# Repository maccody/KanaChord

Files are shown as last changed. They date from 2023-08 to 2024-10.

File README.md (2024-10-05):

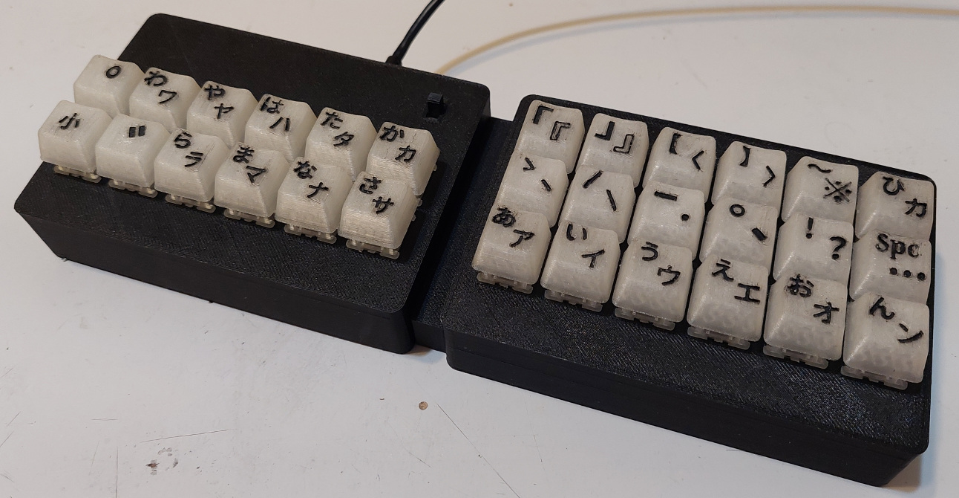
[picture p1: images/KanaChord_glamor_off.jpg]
KanaChord_glamor_off

# KanaChord Keyboard (カナコード・キーボード)
## Overview
KanaChord is an auxiliary keyboard that works in parallel with a standard English keyboard and generates Unicode keyboard macros to render Japanese Kana characters.  This allows the user to immediately start typing in the Japanese Kana, rather that installing special software and switching language input modes on a single keyboard.  KanaChord Keyboard can assist the Japanese learner by providing a means to improve their skills by writing in Japanese, in addition to reading and speaking.  Note that during the composing of this README, KanaChord Keyboard was used to type the Kana characters displayed.

The Japanese writing system consists of three components: Kanji, Hiragana, and Katakana. Kanji consists of Chinese logography and conveys main ideas and names in sentences, e.g., 私, 東京, 何 (‘I’, ‘Tokyo’, ‘what’).  There are thousands of unique Kanji characters.  Hiragana consists of 48 syllabic characters that are used for some words of Japanese origin and grammatical sentence fragments, e.g., あなた, これ, の (‘you’, ‘this’, possessive particle).  Katakana also consists of 48 syllabic characters that are used for foreign loan words and names, e.g., テーブル, クッキー, マック (‘table’, ‘cookie’, ‘Mac’).  The table below shows the syllabary of Hiragana and Katakana, known collectively as the Kana.
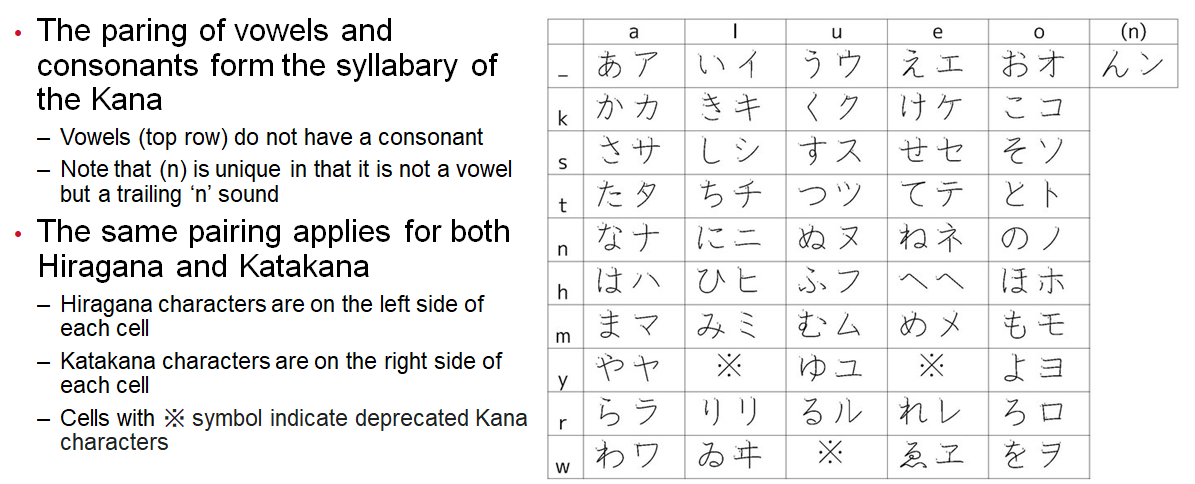
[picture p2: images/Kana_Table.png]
Kana Table


The layout of the Kana Table inspires a chording keyboard input method. Chording is where multiple keys are pressed simultaneously on the keyboard to obtain a desired character output.  The illustration below provides further explanation and demonstration of how chording is used on the KanaChord Keyboard.
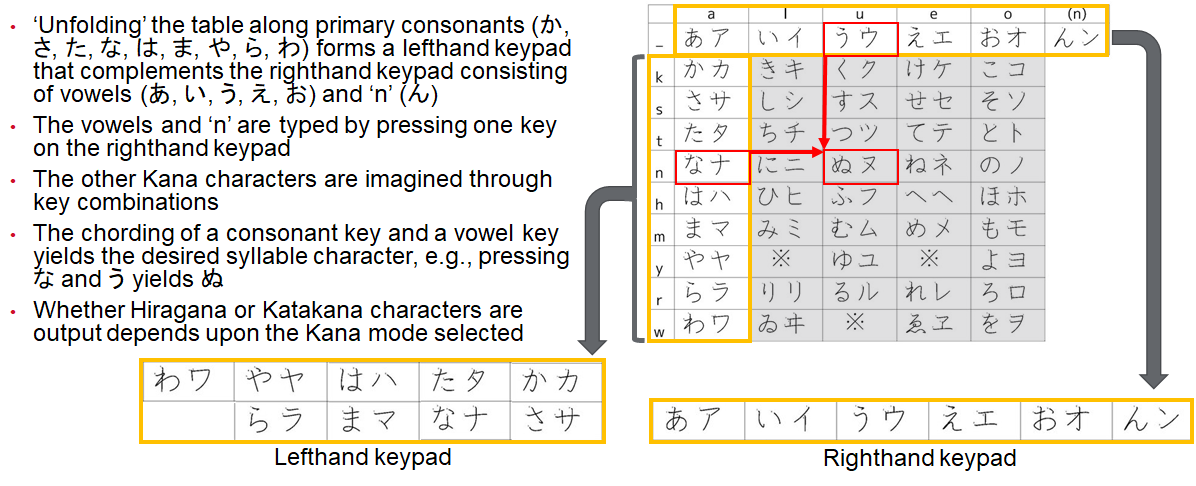
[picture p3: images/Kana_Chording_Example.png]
Kana Chording Example

## Features
KanaChord includes dynamic key coloring that provides indication of character type, Kana mode, and error feedback.  The three Shift keys on the left keypad are normally white:
- Voicing mark, a.k.a. dakuten or ten-ten (ﾞ),
- Plosive mark, a.k.a. handakuten or maru (ﾟ),
- Small characters, a.k.a. chiisai (小), also used to ‘shift’ to alternate punctuation and special characters.

Punctuation keys on the top two rows of the right keypad are also normally white:
- Vertical iteration mark (〳,〴,〵), continuation mark (ー), and separation (・) characters ,
- Sentence pausing (、) and ending characters (。, ! , ?),
- Wide space and ellipsis (…) characters,
- Commonly-used quotation (「, 」,『, 』), bracket (【, 】,〈, 〉), and special (〜,※) characters.

The Kana and horizontal iteration mark (ゝ,ゞ,ヽ,ヾ) keys are green for Hiragana mode or blue for Katakana mode, as selected by the mode key (ひカ) at upper right-hand corner of the right keypad.
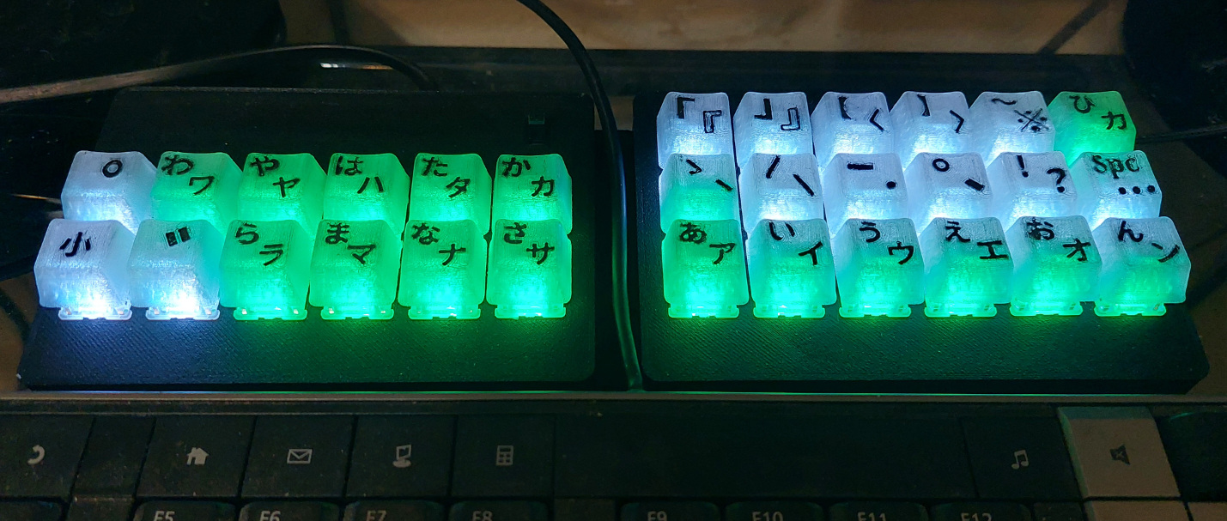
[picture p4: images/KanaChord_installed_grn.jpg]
KanaChord_installed_grn

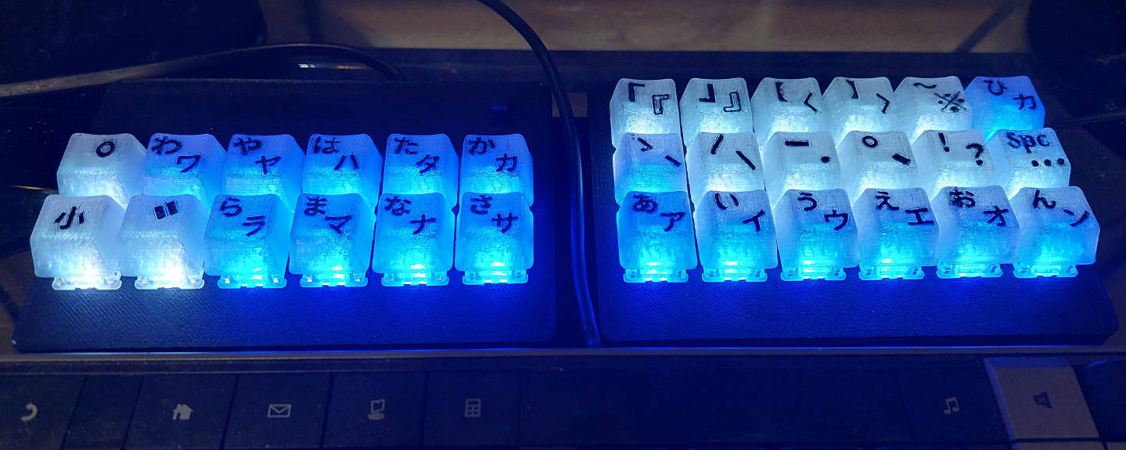
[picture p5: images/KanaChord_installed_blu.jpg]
KanaChord_installed_blu


Feedback is provided to the user for incorrect key combinations by changing those keys red.  Releasing the keys will cause the keys to revert to their original colors.  Some examples are provded below:

Keyboard error lighting with press of ! and お key combination.
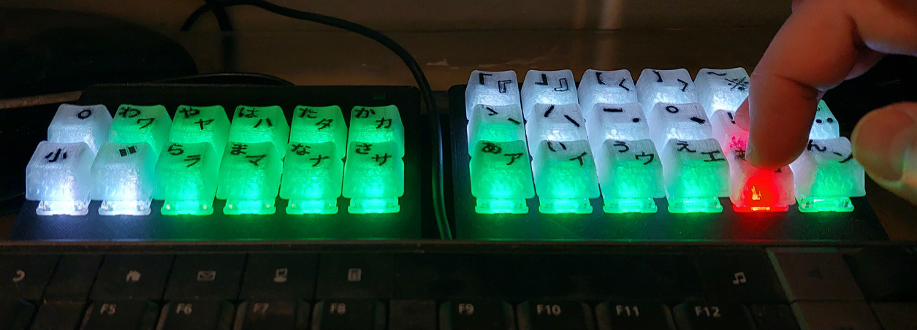
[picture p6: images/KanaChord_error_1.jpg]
KanaChord_error_1


Keyboard error lighting with press of ﾞ, な, and あ key combination.
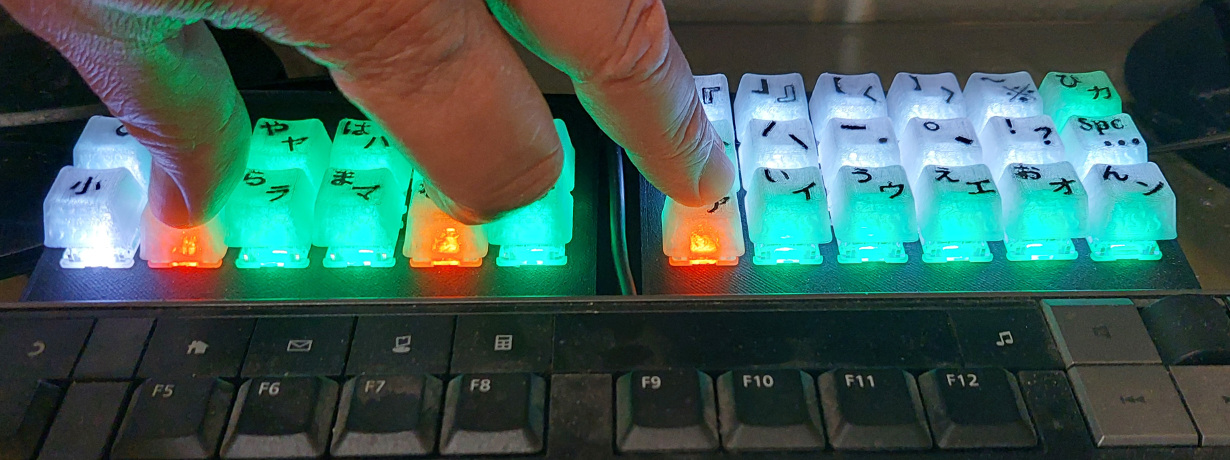
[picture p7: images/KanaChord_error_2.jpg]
KanaChord_error_2


A slide switch above the か key provides three user-selectable Unicode key sequences to support different computer platforms:
- Four-characer hexidecimal Unicode value, followed by Alt-X: Supports Microsoft Word and Wordpad, and LibreOffice Writer.
- Ctrl-Shift-u, followed by four-character hexidecimal Unicode value: Supports Linux applications like LibreOffice Writer and Firefox.
- Option key, followed by four-character hexidecimal Unicode value: Support MacOS applications (not yet tested).

## Implementation Overview
The primary electical componets of the KanaChord Keyboard are a Raspberry Pi Pico (RP2040) microcontroller, an Adfruit NeoKey 5x6 Ortho Snap-Apart keyboard PCB, and thirty Cherry MX mechanical key switches.  The keycaps and keyboard enclosure are 3D printed designs created with TinkerCAD.  Blank keycaps and an OpenSCAD tight-fit box generator were found on Thingiverse.  No special hardware, such as screws are needed to mount the electrical components and assemble the enclosure.  Details on the electronics, enclosure, and their assembly can be found in the hardware subdirectory.

Kanachord's software was developed with the Arduino IDE (version 1.8.19) and Earle Philhower's RP2040 board support package.  The USB Keyboard library, Adafruit Neopixel library, and Mark Stanley's Key and Keypad libraries provided critical software functions.  Details on the software can be found in the software subdirectory.

## Hardware and Software Licenses
Cc_by-nc-nd_icon svg
KanaChord's circuit design and the STL files for the keycaps, component mounting parts, and enclosure parts are placed under Creative Commons Attribution-NonCommercial-NoDerivatives license.

GNU_GPL_V3
KanaChord's source code that I wrote (KanaChord.ino, kana.h, kbd_mgt.cpp, and kbd_mgt.h) are placed under GNU General Public License, Version 3.0.

The slightly-modified versions of Mark Stanley's Key and Keypad libraries (Key2040.cpp, Key2040.h, Keypad2040.cpp, and Keypad2040.h) fall under the license of the original sources.

## Feedback is Welcome!
My goal is to provide an axuilary keyboard that is useful to those who want to start writing in Japanese, while learning Japanese.  I hope to have provided operational features, keycaps, and Asian special characters that would most likely be used.  If you have recommendations for additional features, alternate keycaps, or Asian special characters, please let me know.  I will accomodate as many recommendations as feasible.

## The Future of KanaChord Keyboard
As, mentioned above, KanaChord Keyboard outputs only Kana Unicode, not Kanji Unicode.  This is an obviously glaring omission for writing in Japanese.  A software IME (Imput Method Editor) that accepts Kana Unicode input could be used to make up for this shortcoming.  This takes away from the goal of not needing to install special software.

To that end, I have developed the next version of this keyboard, which also outputs Kanji Unicode. I call it [KanaChord Plus Keyboard (カナコード・プラス・キーボード)](https://github.com/maccody/KanaChordPlus), which can output Unicodes for over 6,100 of the most commonly-used Kanji and over 6,200 of the most commonly-used Japanese words containing Kanji. The user can select them as they type the appropriate onyomi (Chinese), kunyomi (Japanese), or nanori (name) readings using the Kana. This will help the user learn Kanji, as they learn the proper readings and pronunciations from the Kana typed.

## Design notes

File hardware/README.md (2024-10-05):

# KanaChord Hardware

## Electronics Components
KanaChord Keyboard uses following electronics parts:
- 1 x Raspberry Pi Pico microcontroller
- 1 x [Adfruit](https://www.adafruit.com) [NeoKey 5x6 Ortho Snap-Apart Mechanical Key Switches w/ NeoPixel - For MX Compatible Switches](https://www.adafruit.com/product/5157)
- 30 x Cherry MX RGB frame-mount mechanical key switches, e.g., [Cherry MX Brown Switches](https://www.cherrymx.de/en/cherry-mx/mx-original/mx-brown.html) (does not count spares)
- 1 x BC547 (or equivalent) NPN transistor
- 1 x 2.2 Kohm 1/8 Watt resistor
- 1 x 6.8 Kohm 1/8 Watt resistor
- 1 x Three-position (NC-NO-NC) slide switch (E-Switch Slide Switches 500SSP3S2M1QEB, Mouser 612-500SSP3S2M1QEB)
- 27 x 0.1" Spacing Row Right Angle Headers (does not count spairs), e.g., [Schmartboard brand](https://schmartboard.com/qty-10-0-1-spacing-40-single-row-right-angle-headers-920-0076-01/)
- 2 x Seven-position ITT connector shell - (e.g., Adafruit [Large Single Row Housing Pack](https://www.adafruit.com/product/3146))
- 3 x Five-position ITT connector shell - (e.g., Adafruit [Small Single Row Wire Housing Pack](https://www.adafruit.com/product/3145))
- 1 x Four-position ITT connector shell - (e.g., Adafruit [Small Single Row Wire Housing Pack](https://www.adafruit.com/product/3145))
- 1 x Three-position ITT connector shell - (e.g., Adafruit [Small Single Row Wire Housing Pack](https://www.adafruit.com/product/3145))
- 27 x Female crimp contact pins (does not count spares)
- 5 x Male crimp contact pins (does not count spares)
- 1 x 12 inches of Forty-conductor ribbon cable 
- 1 x USB A to USB Micro B cable
- Heat-shrink tubing for enclosing the unidirectional level shifter

## Keyboard Schematics
Below is a pictorial schematic of the keypad portion of the KanaChord keyboard.

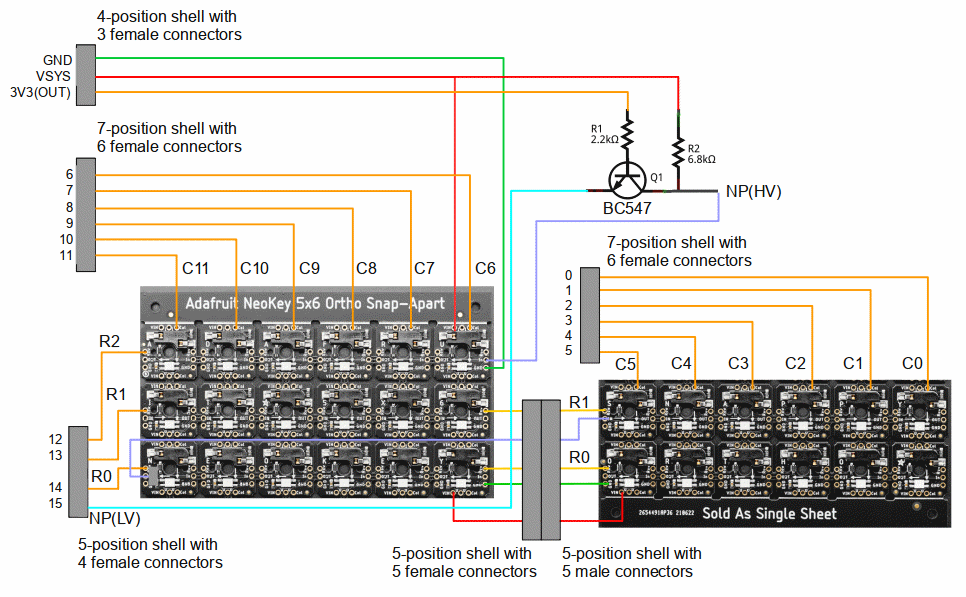
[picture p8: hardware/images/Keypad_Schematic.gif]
Keypad_Schematic


While the Neopixels of the Ortho Snap-Apart board can opperate at 3.3 Volts, the 3.3-Volt regulator on the Pico cannot supply enough current.  Therefore, the Neopixels are powered by the Pico's 5-Volt VSYS output.  Consequently, a unidirectional level shifter is used to convert the low-voltage Neopixel signal, NP(LV), to a high-voltage Neopixel signal, NP(HV).  The BC547 and resistors are used to implement the unidirectional level shifter circuit.

Below is a pictorial schematic of the Raspberry Pi Pico portion of the KanaChord keyboard.

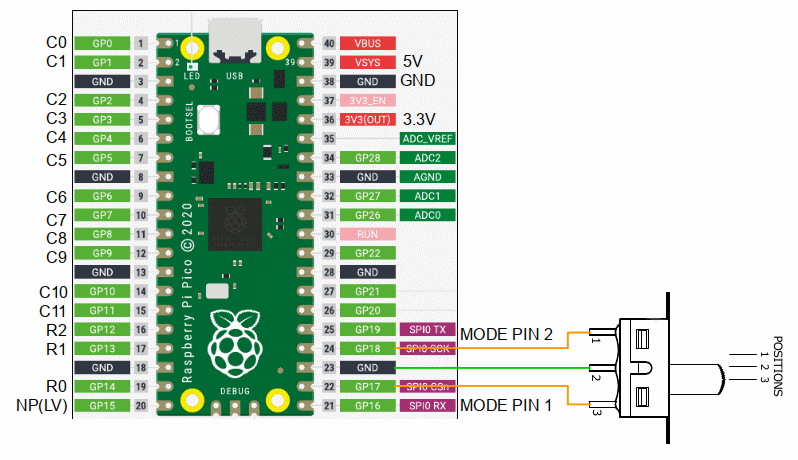
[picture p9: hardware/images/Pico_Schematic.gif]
Pico_Schematic


The right-angle header pins are soldered in 'gull-wing' fashion to pins 1 through 20, 22 through 24, and 36 through 39 of the Pico.  Note that the slide switch is not soldered directly to the Pico.  Instructions found in the Electrical Assembly will describe the wiring harness that is used.

## Electrical Assembly 
### Keypad Preparation 
Before assembly, the snap-apart keyboard must be broken into two pieces to form two PCBs (Printed Circuit Boards) for the left and right keypad assemblies.  As shown in the pictoral schematic above and the pictures below, cut apart the keyboard so that the bottom two rows form the left keypad and the top three rows form the right keypad.  Rather than actually bending the PCB to snap it, it is recommended to use a thin saw to cut the bridges between the rows.  DO NOT cut off the blank sections on the top and bottom of the PCB, as the mounting holes will be used to help position the keypads in the keyboard enclosure.

### Left Keypad Wiring 
The wiring of the left keypad assembly is shown in the picture below.  Take note the direction and length of the wires that extend from the left-hand keypad PCB.

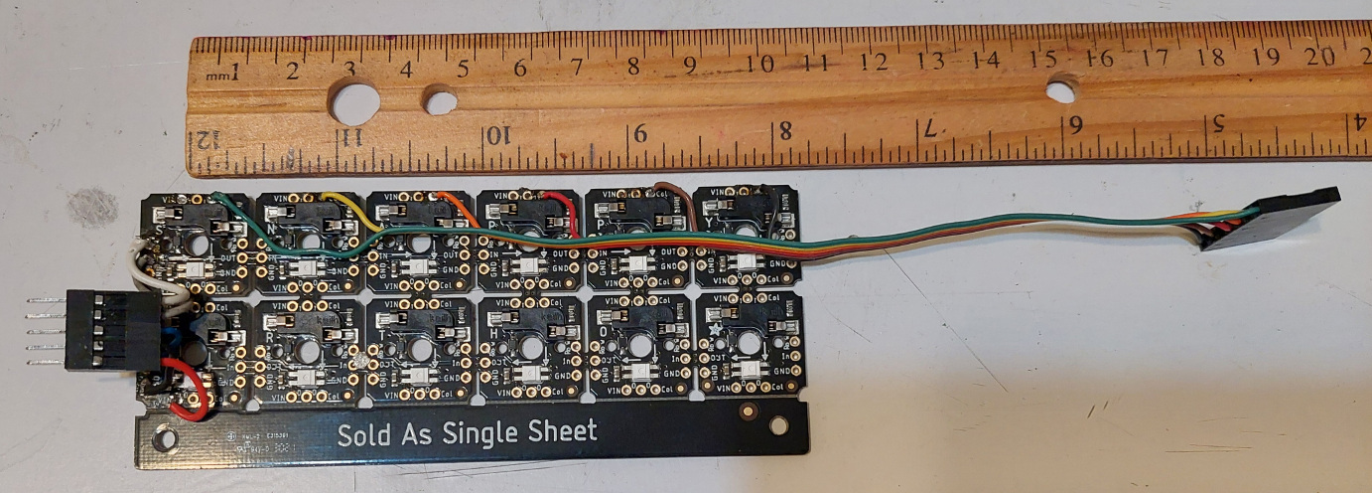
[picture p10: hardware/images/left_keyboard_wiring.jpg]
left_keyboard_wiring


First, cut a six-conductor section of ribbon cable with a length of approximatly 19 cm (7.5 inches).  This will be the column cable for the left keypad.  Separate out the individual conductors for about 3 cm (one inch), attach six (6) female crimp terminals, and insert the terminals into a seven (7) terminal connector shell.  Note that there will be an unused place between the terminal pins for Columns 1 and 2, which is Ground Pin 3 on the Pico. Then, as shown in the picture, start at the left end of of the keypad PCB and solder a conductor to a column solder pad. Work towards the right end of the keypad, shortening the length of the conductor to match to the column solder pad location, while keeping the ribbon cable parallel to the PCB. Note that during installation, this cable will fold over to attach to Pins 1 through 7 on the Pico.

Next, create the male keypad interconnect harness using five (5) male crimp terminals. This is a short cable, with a length of approximately 3 cm (1.25 inches), it is recommended to use separate wires, rather than a ribbon cable. A five (5) terminal connector shell is used for this harness. Use the pictorial schematic above for wiring directions. This completes the wiring of the left keypad assembly.

### Right Keypad Wiring 
The wiring of the right keypad assembly is shown in the picture below. Again, take note of the direction and length of the wires that extend from the right-hand keypad PCB.

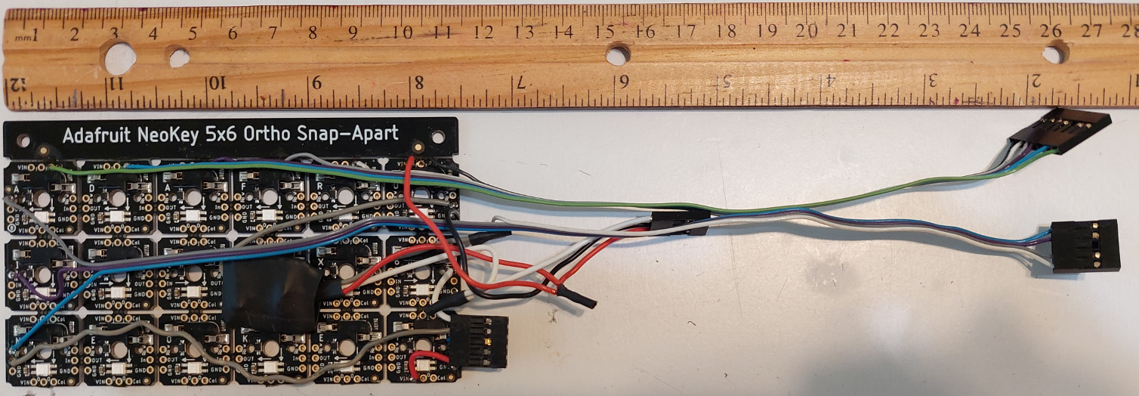
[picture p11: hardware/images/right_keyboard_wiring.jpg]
right_keyboard_wiring


First, cut a six-conductor section of ribbon cable with a length of approximatly 26 cm (10.25 inches).  This will be the column cable for the right keypad.  Separate out the individual conductors for about 3cm (1.25 inches), attach six (6) female crimp terminals, and insert the terminals into a seven (7) terminal connector shell.  Note that there will be an unused place between the terminal pins for Columns 9 and 10, which is Ground Pin 13 on the Pico. Then, as shown in the picture, start at the left end of of the keypad PCB and solder a conductor to a column solder pad. Work towards the right end of the keypad, shortening the length of the conductor to match to the column solder pad location, while keeping the ribbon cable parallel to the PCB. Note that during installation, this cable will fold over to attach to Pins 9 through 15 on the Pico.

Next, create the female keypad interconnect harness using five (5) female crimp terminals. This is a short cable, with a length of approximately 3 cm (1.25 inches), it is recommended to use separate wires, rather than a ribbon cable. A five (5) terminal connector shell is used for this harness. Use the pictorial schematic above for wiring directions.

Now, cut a four-conductor section of ribbon cable with a length of approximatly 28 cm (11 inches).  This will be the row cable for the right keypad.  Separate out the individual conductors for about 3 cm (1.25 inches), attach four (4) female crimp terminals, and insert the terminals into a five (5) terminal connector shell.  Note that there will be an unused place between the terminal pins for Rows 0 and 1, which is Ground Pin 18 on the Pico. Note that three of the ribbon cable conductors attach to the Row solder pads on the right keyboard PCB, while one conductor attaches to the signal input of the level shifter circuit. Note that during installation, this cable will fold over to attach to Pins 16 through 20 on the Pico.

Assmble the unidirectional level shifter circuit on a small piece of prototyping board with solder pads or as otherwise desired.  The idea is to keep the resulting assembly small and relatively flat.  In the implementation shown in the picture, judicious application of heat-shrink tubing was performed to prevent short circuits. ***Note: Instructions for constructing of an equivalent, free-form-wired level shifter can be found on the [KanaChord Plus Hardware page.](https://github.com/maccody/KanaChordPlus/tree/main/hardware#level-shifter-assembly)***  The circuit is wired into the power harness, which is approximately 10 cm (3.5 inches) long.  The power harness has three (3) female crimp connectors that are inserted into a four (4) terminal connector shell.  Note that there will be an unused place between the Ground and 3V3(OUT) pins, which is the 3.3V_EN pin 37 on the Pico.  Consult the pictorial schematic above for the wiring of the level shifter circiut, with the output of the level shifter connected to the Neopixel input and the power harness 5V and Ground to the right keyboard PCB. During installation, the power harness connector will attach to Pins 36 through 39 on the Pico. This completes the wiring of the right keypad assembly.

The macro mode slide switch is soldered to a three-wire harness that is 5 cm (2 inches) long.  The harness has three (3) female connector pins crimped on and placed within a three-position connector shell. Consult the pictorial schematic above for the wiring of the switch harness. During final assembly, the connector will be placed on the header pins at positions 22 through 24.

## 3D-Printed Keycaps
The keycaps for the KanaChord Keyboard were created in TinkerCAD, as shown in the illustration below.  The STL files for the left-hand and right-hand keycap sets can be viewed with the Github STL viewer by clicking on the STL files listed above.

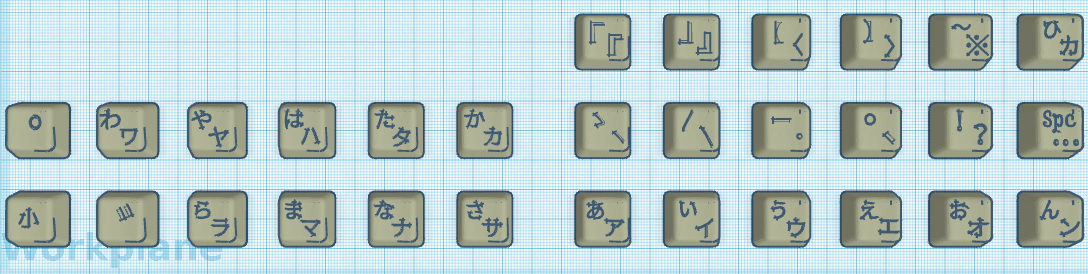
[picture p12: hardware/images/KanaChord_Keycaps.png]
KanaChord_Keycaps


The blank keycap from makerhack's (Chris Garrett) [Custom Cherry MX Keycaps](https://www.thingiverse.com/thing:4702109) was used as the source keycap.  The design is licensed under the [Creative Commons - Attribution license](https://creativecommons.org/licenses/by/4.0/). The Kana and special charaters are text objects converted to TinkerCAD 'holes' that are combined with blank keycaps to form insets. The keycaps were sliced with Cura using the Standard Quality (0.2mm) setting, with 20% infill using the gyroid infill pattern, and Tree supports were used. The keycaps were printed with untinted PLA to allow light from the Neopixels to shine through. After printing, the insets were filled with black acrylic paint, followed by a coat of flat, clear enamel paint.

## 3D-Printed Enclosure
The enclosure for the KanaChord Keyboard was also created in TinkerCAD, as shown in the illustrations below.  The STL files for the individual components of the enclosure can be viewed with the Github STL viewer by clicking on the STL files listed above.  **NOTE: The STL files for the case, base, and foot parts have been updated since the images below were generated.  The assembly process is still the same.**

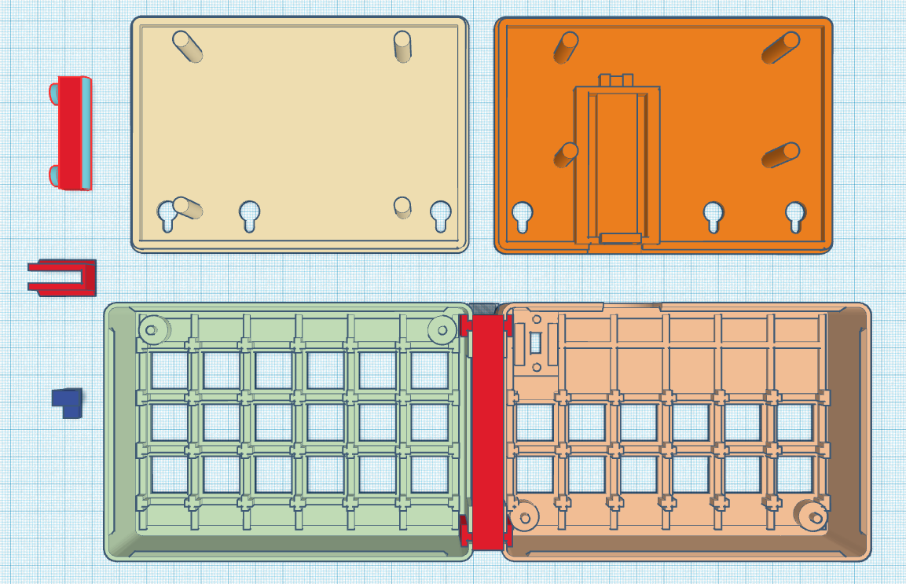
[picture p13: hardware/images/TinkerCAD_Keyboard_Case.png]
TinkerCAD_Keyboard_Case


The left and right keycase enclosures were created using 0707070user's OpenSCAD program [Customizable snap-fit electronics project box enclosure](https://www.thingiverse.com/thing:2866563). It is licensed under the [Creative Commons - Attribution license](https://creativecommons.org/licenses/by/4.0/). The enclosure components are flipped so tha the lids now act as baseplates for the keyboard enclosure. The enclosures were edited to create the key switch holes of the integral keyplates, the switch and Pico mounts, and pass-through holes for the keyboard feet, and the USB cable.  

The enclosure was designed in halves to fit on the build plate of a Crealty Ender 3 Pro 3D printer.  All components were sliced with Cura using the Low Quality (0.28mm), with 20% infill using the standard in-fill pattern, and no supports were used.  The case components were prited in black PLA, although any color can be used, if desired.

## Mechanical Assembly

### Applying PCB Cushions
The keypad PCBs are connected to the key switches via sockets.  To prevent the PCBs from coming loose from the key switches, supports are provided to keep the PCBs in place. Two of these supports are shown in the photo below.

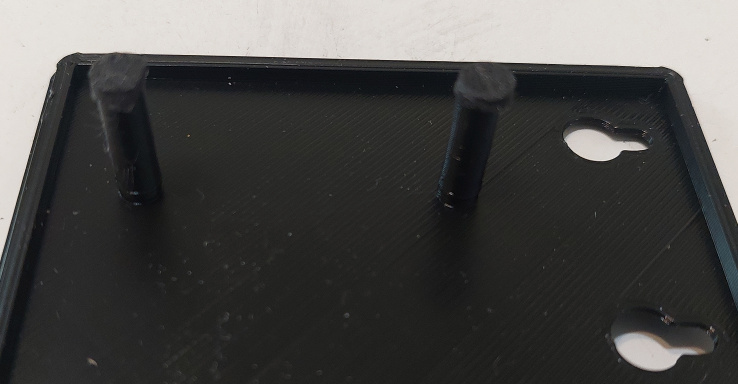
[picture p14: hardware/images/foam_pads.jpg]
foam_pads


The height of each support is such that there is about a 2mm (0.1 inch) gap from the top of the supports to the underside of the PCBs. To fill in the gap, a small disc of 2mm-thick craft foam is attached to top of each support with double-sided adhesive tape.  One way to make the discs is to apply a strip of double-sided tape to a piece of craft foam.  A single-hole hole punch is used to create the discs with the adhesive tape also cut to the same size as the disc.  Eight (8) discs will be needed for the supports.

### Mounting the Raspberry Pi Pico
The Pico is mounted to the left keyboard base by first inserting the end with the USB connector under the bridge of the processor mount at the edge of the keyboard base. Once this is done, push the opposite end of the Pico down into the depression of the processor mount. Finally, slide the retaining clip into the notches in front of the processor mount until the tab of the retaining clip is securely on top of the end of the Pico.

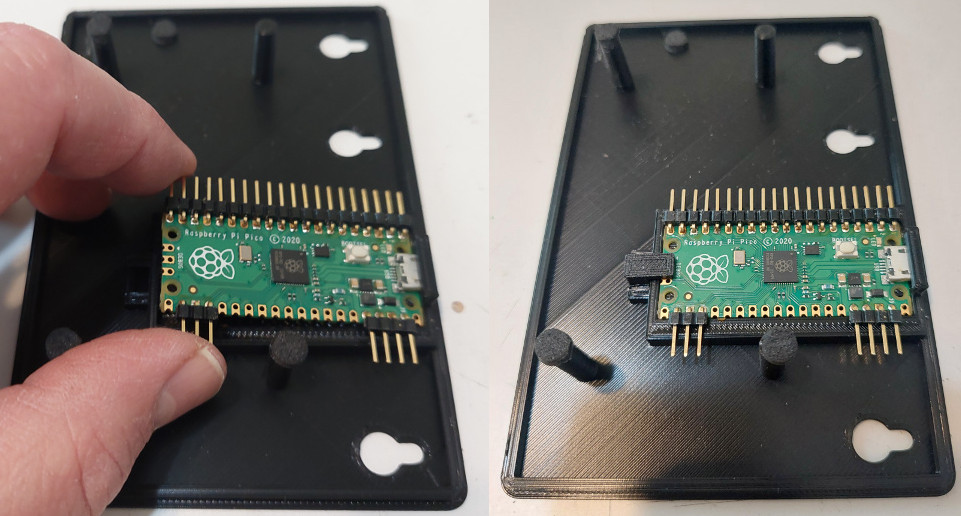
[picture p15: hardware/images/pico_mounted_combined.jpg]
pico_mounted_combined


### Mounting the Macro Mode Switch
The Macro Mode slide switch is placed into the left keyboard enclosure such that the switch handle passes through the hole in the enclosure and the tabs on each end of the switch sit around the two retaining pegs.  Once in place, the switch clip is slid into place around the switch.  Make a note of the order of the wires on the switch and connector, so that the connector is properly connected to the Pico later.

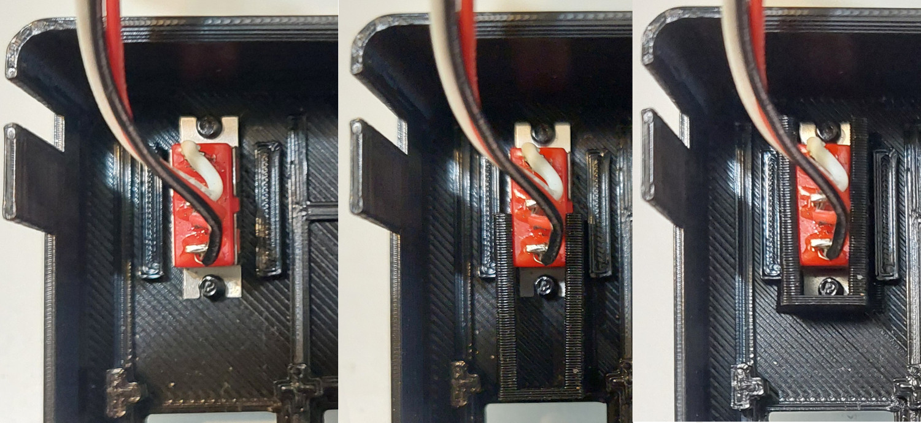
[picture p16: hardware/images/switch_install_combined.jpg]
switch_install_combined


### Break-in the Key Switch Sockets
Prior to mounting the key switches and keypad PCBs, it is highly recommended to 'break in' the key sockets on the keypads.  This is done by inserting a key switch into each key socket at least once.  The key sockets are a little 'stiff' with the first insertion of a switch.  Doing this will make it a bit easier to mount the key switches into the keypads and reduce the possibility of bending the tabs on the key switches.

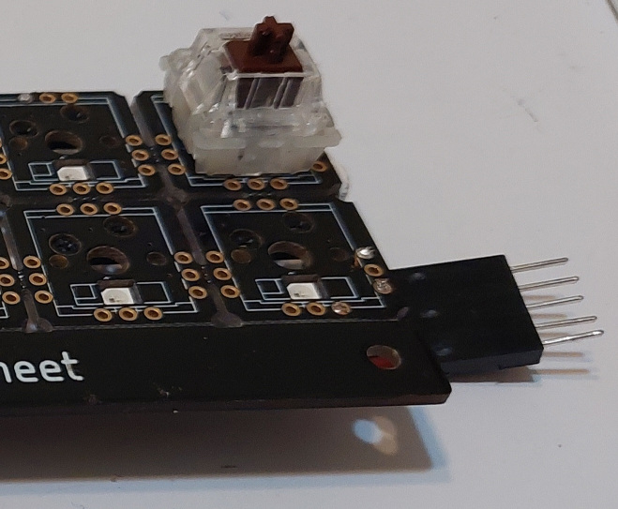
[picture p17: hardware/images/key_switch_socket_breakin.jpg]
key_switch_socket_breakin


### Preparing the Enclosures for the Key Switches
It may be necessary to slightly widen the keyplate holes on the enclosures prior to attaching the key switchs and keypads.  For any give hole, try to insert a key switch without any widening.  If a switch plugs in easily, then no widening is needed.  For those holes needing widening, use a flat-sided jewler's file to slightly widen all sides of the hole.  In practice, it should not take much filing to allow a switch to plug in easily.

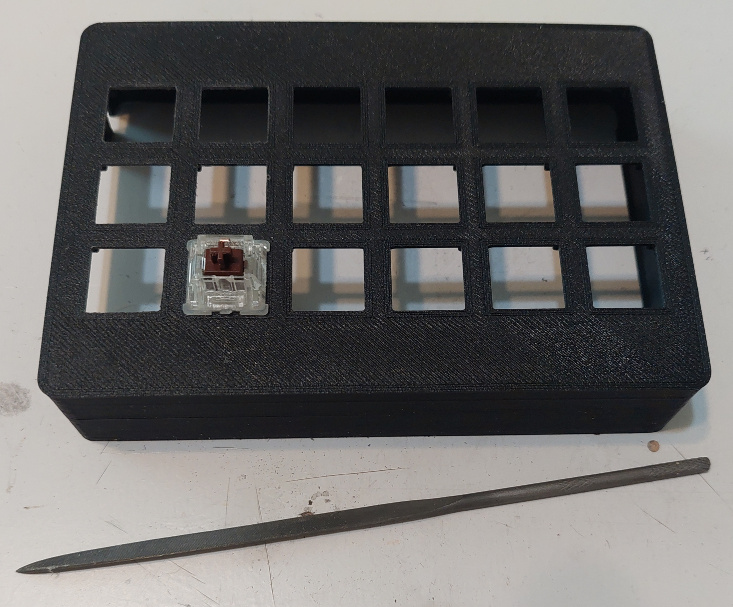
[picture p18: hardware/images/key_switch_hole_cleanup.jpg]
key_switch_hole_cleanup


### Mounting Key Switches and Keypad PCBs to the Enclosures
**NOTE: It has been determined that the positions of the mounting holes on the keypad PCBs can be a bit variant.  If it is found that the kepads will not fit on the mounting posts, it is recommended that the posts be removed.  This results in making it a bit more difficult to initially align the keypad PCBs with the keyplate holes and key switches.**

**UPDATE: The spacing of the mounting posts on the keyboard cases have been updated to better fit the mounting holes on the keypad PCBs.  Follow the recommendation above if fitting problems still occur.**

First, slide on the keyboard bracket on to the right keyboard enclosure.  Make sure that the bracket is inserted such that the side with the tabs flush to the bracket face is inserted first.  Next, place the three-row keypad PCB into right keyboard enclosure. The female keyboard interconnect connector, the column and row cables, and the power harness should slide through the opening in the keyboard bracket. Use the mounting pins, if present, to align the key sockets with the holes of the integral key plate.

Start at one end of the enclosure and insert a key switch through the hole of the keyplate into the socket of the PCB. Place a finger against the key socket, on the bottom side of the PCB, to support key switch insertion. Having a keycap on the switch will make it easier to press the switch in.  Once the switch is inserted, go to the opposite end and insert another key switch as before.  Doing this will stablize the PCB position for inserting the rest of the key switches.  Working from the ends towards the center of the enclosure, plug in more keys until all eighteen switched are plugged in.

Now insert the left keypad PCB into the left keyboard enclosure.  As with the right keypad, align the key socket with the holes in the integral keyplate.  Insert the key switches, again working from both end of the enclosure to the center.  Once all of the key switches are inserted, slide the left keyboard enclosure onto the other side of the keyboard bracket.  While doing this, fold up the male keyboard connector to clear the bracket and then plug it into the female keyboard connector.

After completing these steps the keyboard assembly show look as shown in the picture below.

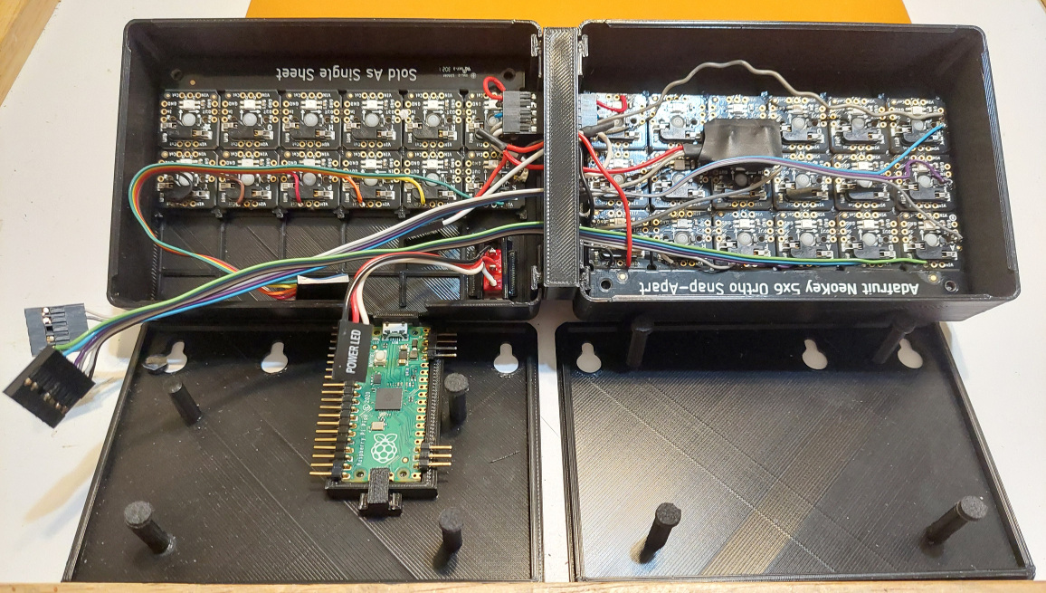
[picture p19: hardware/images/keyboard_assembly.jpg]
keyboard_assembly


### Inserting Connectors onto the Pico
Insert the power harness connector on to pins 36 through 39 on the Pico.  Make sure that the 3.3V wire is connected to 3V3(OUT) (pin 36), the ground wire is connected to GND (pin 38), and the 5V wire is connected to VSYS (pin 39). Then, connect the column cable for the left keypad to pin 1 through pin 7 on the Pico.  The Column 0 (C0) wire should be connected to pin 1.  The picture below shows how the connections should look.

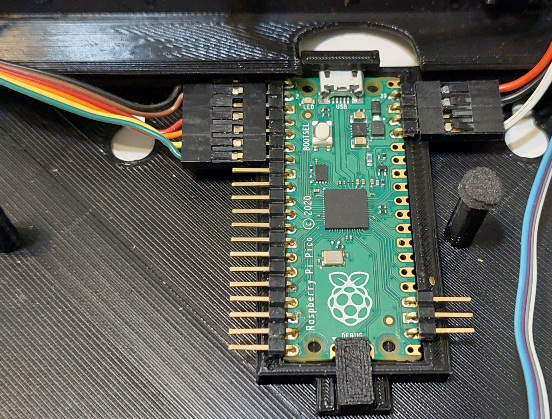
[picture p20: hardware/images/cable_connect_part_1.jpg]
cable_connect_part_1


Next, insert the column cable for the right keypad to pin 9 through pin 15 on the Pico. The Column 6 (C6) wire should be connected to pin 9.  Then, connect the row cable for the right keypad to pin 16 through pin 20 on the Pico. The Row 2 (R2) wire should be connected to pin 16 and the Neopixel low voltage (NP(LV)) wire should be connected to pin 20. The picture below shows how the connections should look.  

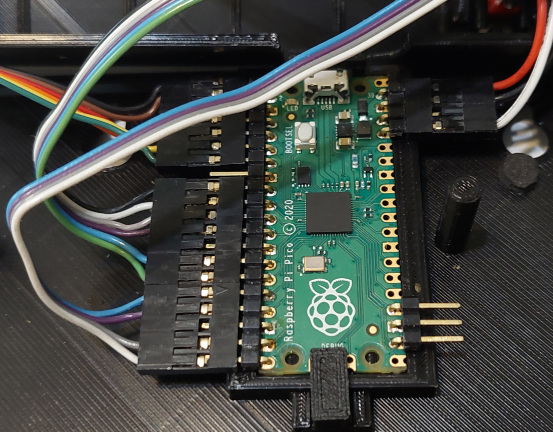
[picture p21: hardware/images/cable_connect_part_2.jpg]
cable_connect_part_2


Finally, insert the connector for the Macro Mode switch onto pins 22 through 24 on the Pico.  Take note that the wires of the connector are oriented such that the slide switch grounds pin 22 when switch handle is pushed towards the center of the left keyboard enclosure and pin 24 is grounded when the switch handle is pushed towards the back edge of the left keyboard enclosure. The picture below shows how the connections should look.

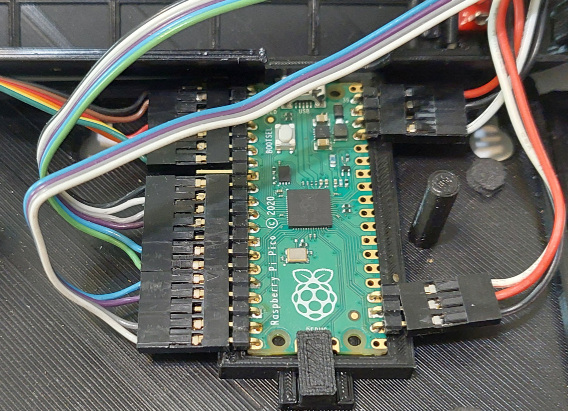
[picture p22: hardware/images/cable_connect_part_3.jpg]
cable_connect_part_3


### Attach Keyboard Bases and Feet
Now that the wiring is completed, the keyboard enclosure can be closed.  Place the right keyboard base onto the bottom of the right keyboard enclosure.  Make sure that the wiring and level shifter do not interfere with the keypad PCB supports pushing up against the bottom of the right keypad.  The keyboard base is a press-fit design, so it should pop into place without too much effort.  Now, fold over the left keyboard base, making sure that the wiring does not interfere with the keypad PCB support pushing up against the bottom of the left keypad.  Snap the left keyboard base into place, as was done with the right keyboard base. The assembly should appear as shown in the picture below.

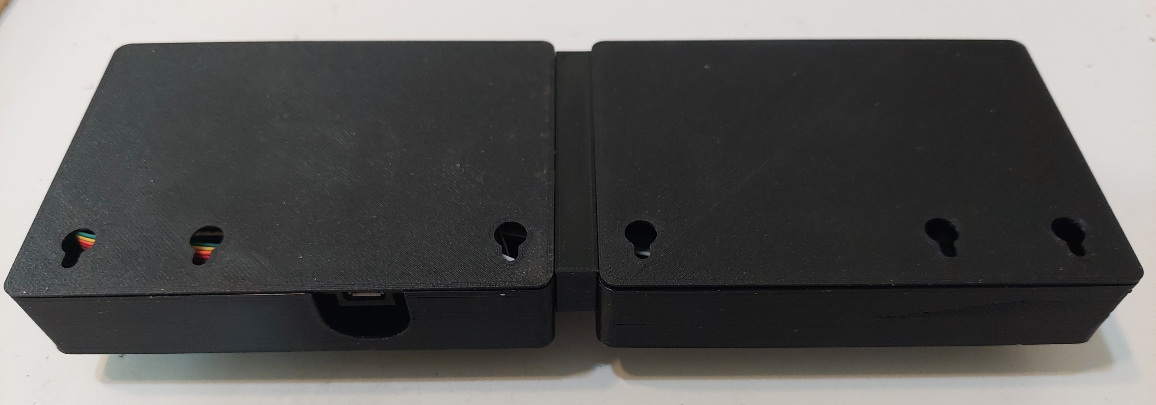
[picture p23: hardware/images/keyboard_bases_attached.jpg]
keyboard_bases_attached


Attach the three keyboard feet by sliding the attachment pegs into the holes and sliding the feet into the slots.  **NOTE: The pegs of the keyboard feet and the holes of the base parts have been updated to a square shape.  This was done to help keep the feet from folding over after insertion.**  If desired, the right and left keyboard feet can be glued into place.  It is not recommended to glue the center foot, as doing so would make it difficult to disassemble the keyboard for maintenance or modification.

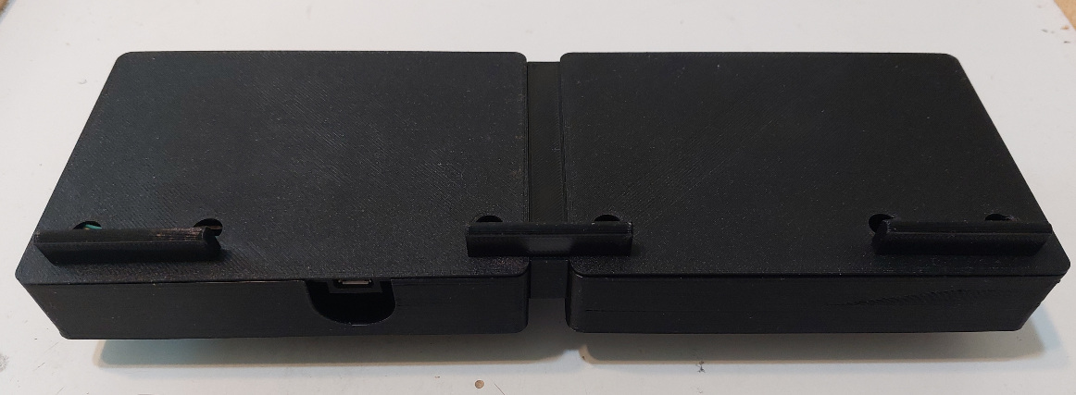
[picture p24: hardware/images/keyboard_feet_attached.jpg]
keyboard_feet_attached


This concludes the hardware construction of the KanaChord Keyboard.  If not already done, program the Pico with the KanaChord software and put the keyboard to use!

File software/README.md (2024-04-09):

# KanaChord Software
KanaChord's software was developed with open-source tools and libraries:
- Arduino Integrated Development Environment (Version 1.8.19),
- Wiring programming language (C++-ish),
- [Earle Philhower's RP2040 Arduino board support package](https://github.com/earlephilhower/arduino-pico),
- Libraries used:
   - [Arduino USB Keyboard Emulation](https://www.arduino.cc/reference/en/language/functions/usb/keyboard/),
   - [Mark Stanley's Arduino Keypad](https://github.com/Chris--A/Keypad),
   - [Adafruit Neopixel](https://github.com/adafruit/Adafruit_NeoPixel).

Note that the source code for the Keypad library has been slightly modified for the RP2040 and the file names have been renamed accordingly.  The output drive current for the keyboard polling lines has been set to 12 milliamps, which is the maximum for the RP2040.  It was found that the default drive current of 4 milliamps provided insufficient current for the keyboard.

A high-level flowchart of the Arduino setup() and loop() functions is presented below:
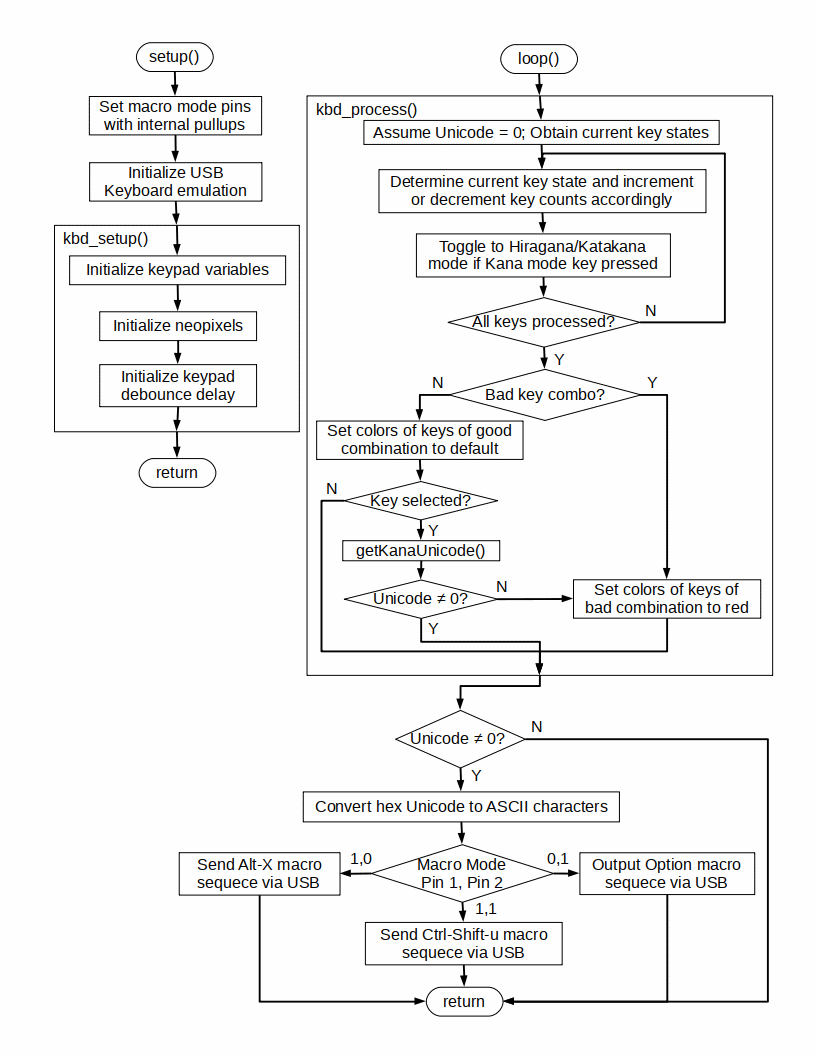
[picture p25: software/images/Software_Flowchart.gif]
Software_Flowchart


A lot of the keyboard processing involves determining whether a pressed key combination is valid or not.  If the combination is invalid, the Neopixels of the pressed key combination are turned red.  If the combination is valid, a Unicode key value is converted to ASCII and sent as part of a macro sequence to the USB device interface for transmission to the computer.  The macro sequence sent is determined by a three-position switch.  The macro sequences are for Microsoft Windows applications (e.g., MS Word, Wordpad, LibreOffice), Linux applications (e.g., LibreOffice, Firefox), and MacOS applications (functionality not tested yet). The setting of the Macro Mode Switch can be change at any time, while not pressing keys, to change the Unicode macro sent.  This is useful when switching between applications that use different Unicode macro sequences. For additional details, consult the commented source code.
## Unicode Data
The file kana.h contains C++ arrays containing the 16-bit Unicode values for Kana (Hiragana and Katakana) characters, and some Chinese/Japanese/Korean punctuation and special characters.  Details on these Unicode blocks can be found in the following PDFs:
- [Official Unicode Consortium Hiragana code chart](https://www.unicode.org/charts/PDF/U3040.pdf)
- [Official Unicode Consortium Katakana code chart](https://www.unicode.org/charts/PDF/U30A0.pdf)
- [Official Unicode Consortium CJK Symbols and Special characters code chart](https://www.unicode.org/charts/PDF/U3000.pdf)
- [Official Unicode Consortium General Punctuation characters code chart](https://www.unicode.org/charts/PDF/U2000.pdf)

The arrays containing the Kana are grouped according Hiragana and Katakana character sets. Individual arrays represent unaugmented (base) characters and augmented characters, i.e., ten-ten, maru, and small (chiisai) characters. Each array is organized by ten 'consonants' (rows) and six 'vowels' (columns).  Special characters are also grouped according to Hiragana and Katakana character sets, although this results in most characters being duplicates in these sets. This was done to simplify the code used to access the arrays.  

The function getKanaUnicode(), defined in kbd_mgt.cpp, takes inputs of Kana mode, special character mode, shift mode, and index row and column to select a Unicode character value. If the selected Unicode value is 0x0000, then an illegal key has been selected.

## Compiling and Uploading the KanaChord Keyboard Software
First, start the Arduino IDE and click on Tools on the menubar and select Manage Libraries from the drop-down menu.  Install Earle Philhower's RP2040 Arduino board support package and the Arduino USB Keyboard emulation library.  Next, select Tools on the menubar and select Board from the drop-down menu.  Select 'Raspberry Pi RP2040 Boards' from the displayed cascade menu, and then 'Raspberry Pi Pico' from the next displayed cascade menu.

Now that Pico board support is in place, adjust the board parameters as follows (also shown in the picture below):
- Flash Size: "2MB (no FS)"
- CPU Speed: "120 MHz"
- Optimize: "Optimize More (-O2)"
- RTTI: "Disabled"
- Stack Protector: "Disabled"
- C++ Exceptions: "Disabled"
- Debug Port: "Disabled"
- Debug Level: "None"
- USB Stack: "Pico SDK"
- IP/Bluetooth Stack: "IPv4 Only"
- Upload Method: "Default (UF2)"

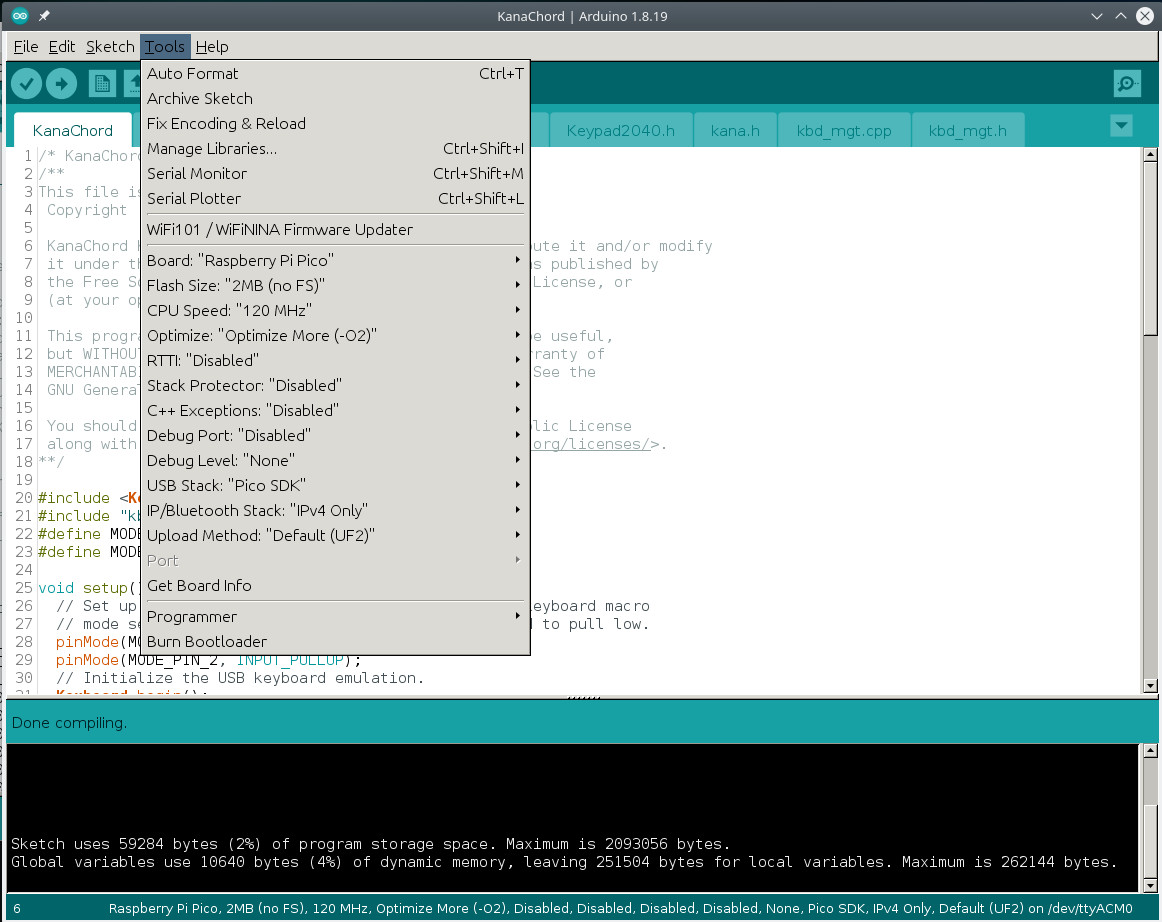
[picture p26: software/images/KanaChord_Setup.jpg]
KanaChord_Setup


Place the KanaChord Keyboard source files into a new directory named KanaChord. Load KanaChord with the Arduino IDE. Click the Verify button to ensure that the KanaChord source code compiles successfully. The compile status should be as shown in the picuture below.  If compiling fails, check that all needed files and libraries are installed and the configuration is correct.

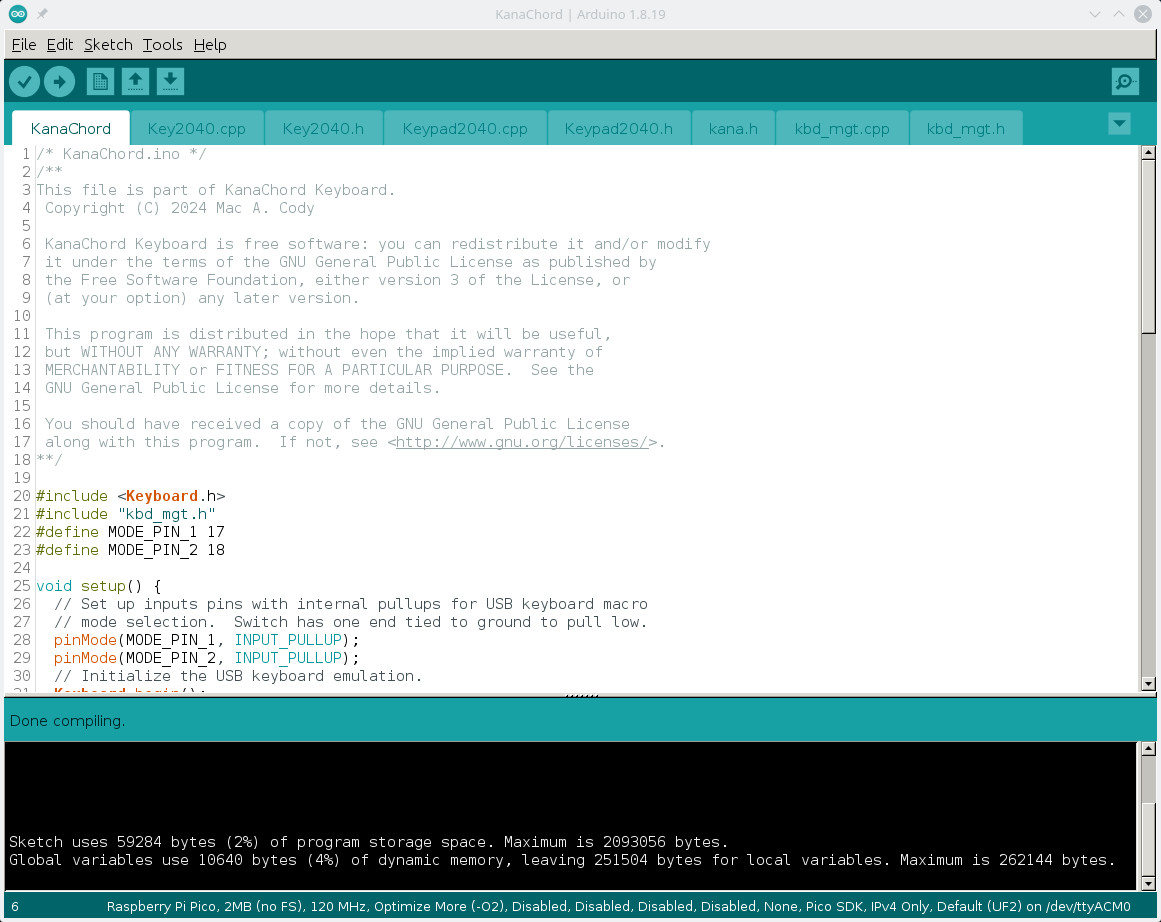
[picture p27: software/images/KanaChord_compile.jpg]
KanaChord_compile


Now, connect the Raspberry Pi Pico to the computer with a USB cable.  Click the Upload button to compile the KanaChord source code and upload the compiled binary to the Pico.  If the upload fails, make sure that the USB cable is securely connected to the Pico and the computer performing the programming. It may also be necessary to hold down the BOOTSEL button on the Pico while plugging the USB cable into the computer.

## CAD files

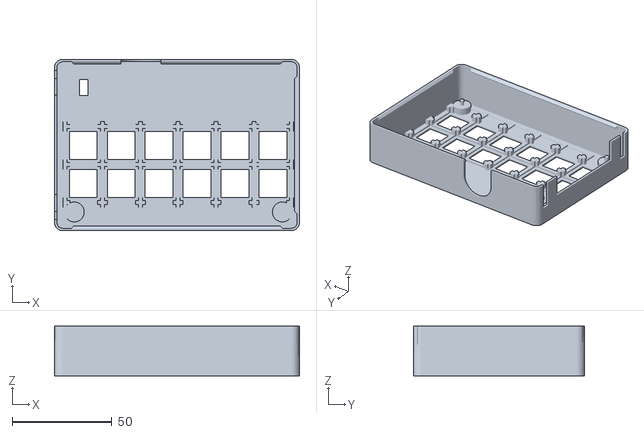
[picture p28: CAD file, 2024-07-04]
hardware/KanaChord-keycase-left.stl
123.0 x 86.0 x 25.0

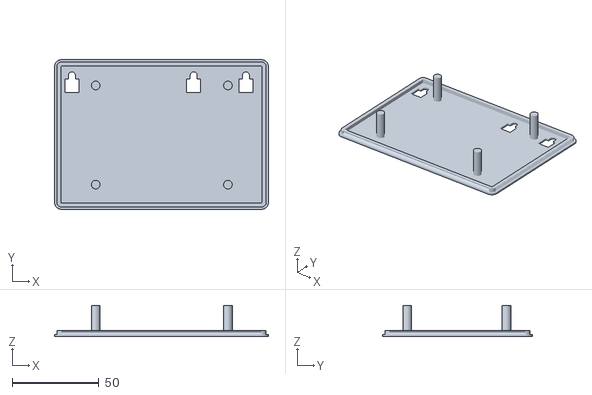
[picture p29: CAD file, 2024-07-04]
hardware/KanaChord-keybase-right.stl
123.0 x 86.0 x 18.0

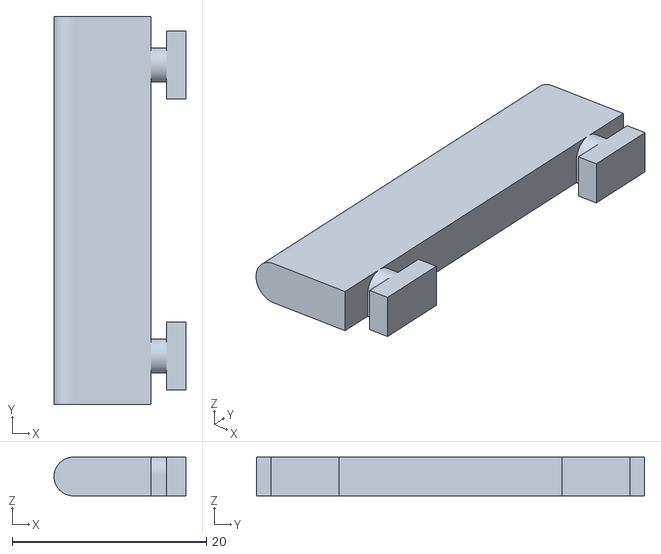
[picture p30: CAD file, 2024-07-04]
hardware/KanaChord-foot.stl
13.6 x 40.0 x 4.00

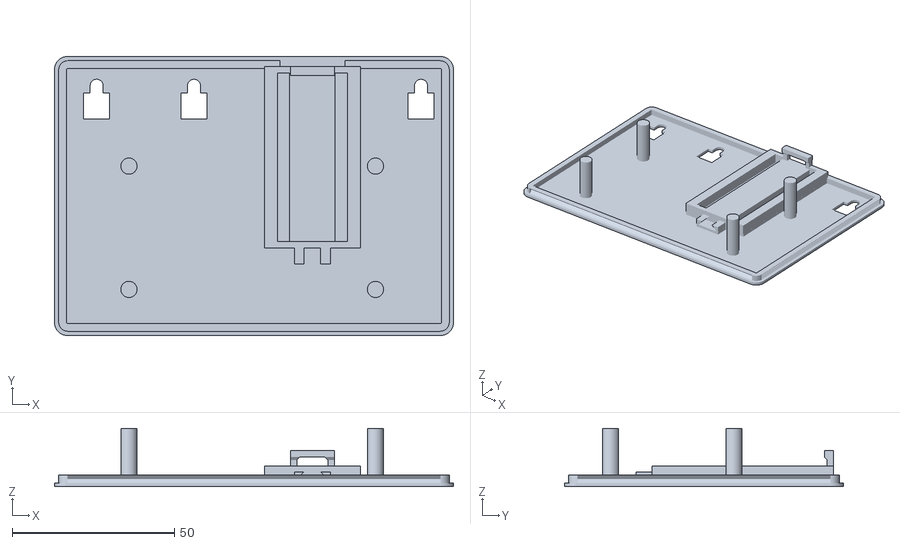
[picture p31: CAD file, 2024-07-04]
hardware/KanaChord-keybase-left.stl
123.0 x 86.0 x 18.0

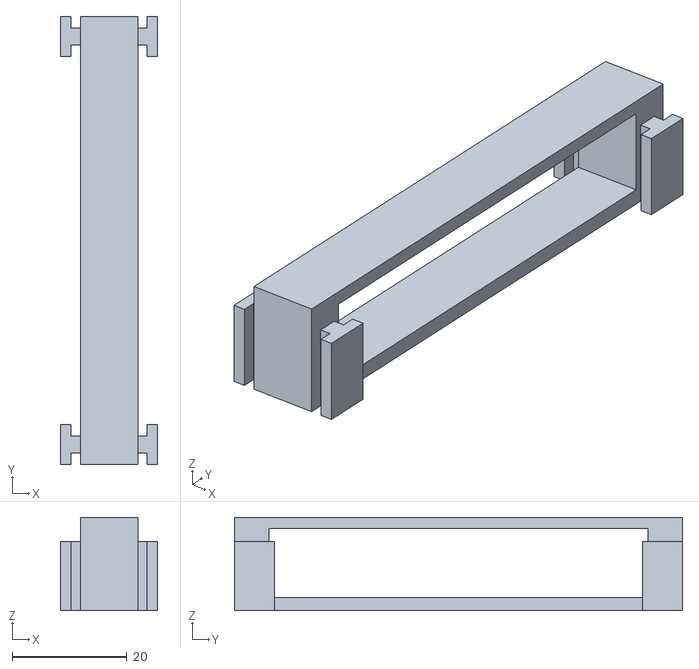
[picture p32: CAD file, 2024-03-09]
hardware/KanaChord-keyboard_bracket.stl
16.9 x 78.0 x 16.2

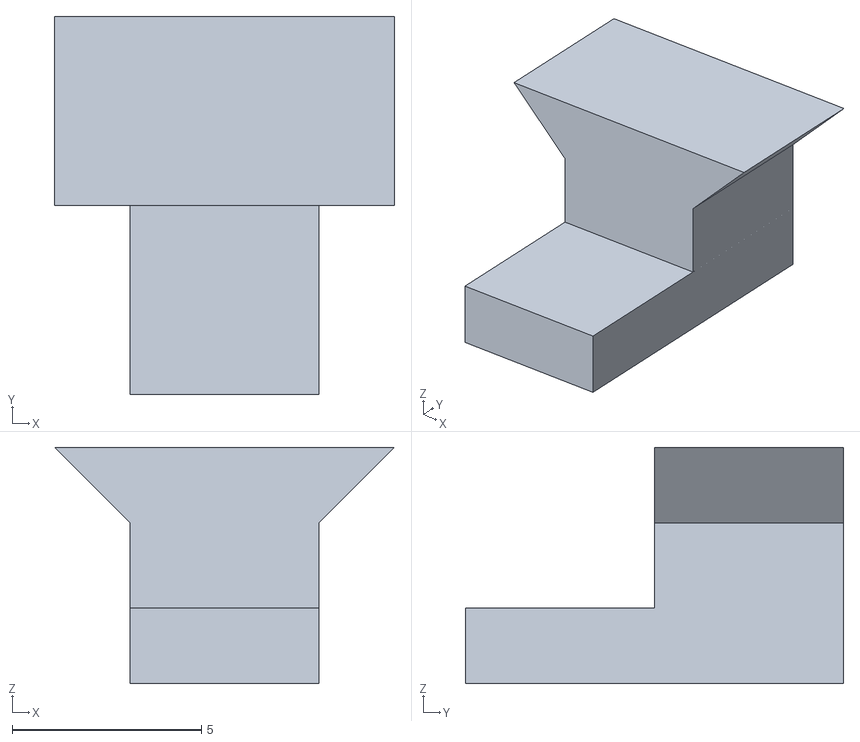
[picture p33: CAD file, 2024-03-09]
hardware/KanaChord_pico_clip.stl
8.99 x 10.0 x 6.25

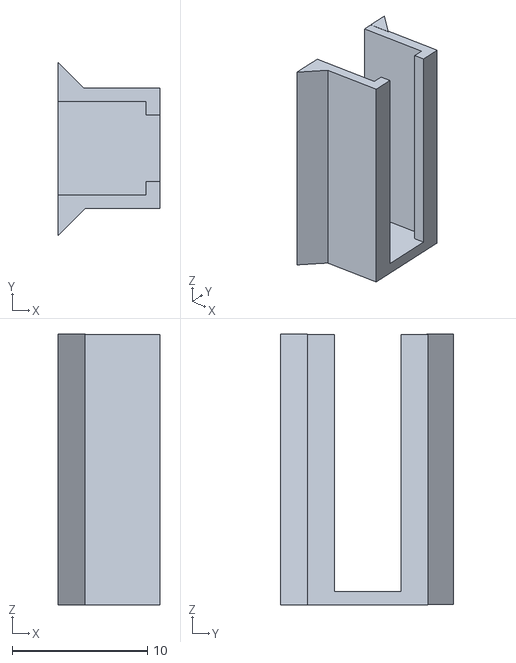
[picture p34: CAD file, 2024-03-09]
hardware/KanaChord_switch_clip.stl
7.50 x 12.8 x 20.0

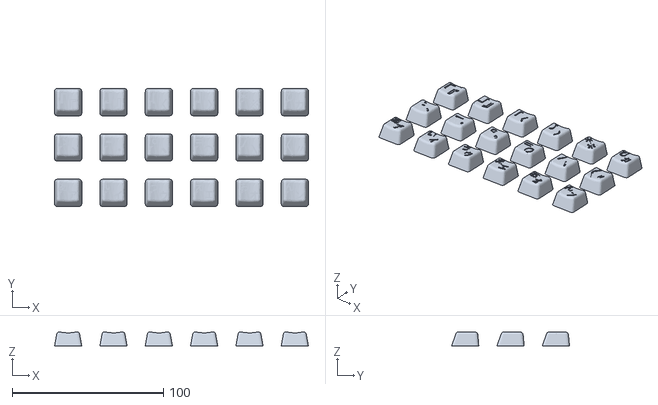
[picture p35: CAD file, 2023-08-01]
hardware/KanaChord_RightHandKeys.stl
168.1 x 78.1 x 9.45

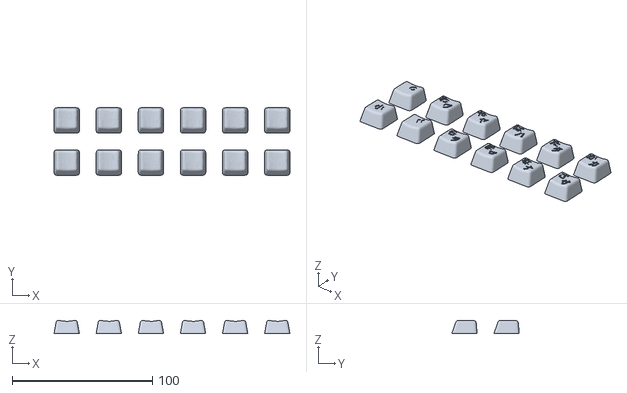
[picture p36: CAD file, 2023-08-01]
hardware/KanaChord_LeftHandKeys.stl
168.1 x 48.1 x 9.45

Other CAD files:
hardware/KanaChord-keycase-right.stl

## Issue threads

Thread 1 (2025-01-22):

"Unicode Hex Input" required for macOS kana entry

peterjc, 2025-01-22:
Quoting the README:

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

Quoting your [macOS code](https://github.com/maccody/KanaChord/blob/62d47a81b765159cc38a7afdeb9cba8982e758e6/software/KanaChord.ino#L53) version:

```
      // MacOS Unicode entry sequence.
      Keyboard.press(KEY_LEFT_ALT);
      delay(20);
      Keyboard.write(n0);
      Keyboard.write(n1);
      Keyboard.write(n2);
      Keyboard.write(n3);
      Keyboard.releaseAll();
      delay(20);
```

However, there is a caveat you might want to mention. First the user _must_ enable "Unicode Hex Input" as a input source within the macOS keyboard settings (along side where they likely already have "Japanese = Romaji" and/or "Japanese - Kana"). This is right at the end of the list by coutnry under "Other" in macOS Sequoia.

With that done this works:

1. If not already active, toggle to the "Unicode Hex Input" via the top right menu or a keyboard shortcut (in this mode my keyboard otherwise seems to remain in ABC mode, I can type English just fine).
2. Observe a blue "U+" icon appear briefly below the cursor
4. Press-and-hold KEY_LEFT_ALT aka "option"
5. Press "3" (top row or number pad fine)
6. Press "0"
7. Press "4"
8. Press "2"
9. Release KEY_LEFT_ALT
10. The hiragana あ appears
11. Optionally return to the original keyboard mode, again I see a blue icon just below the cursor.

I have not tested your code, just pressing buttons on a QWERTY keyboard.

peterjc, 2025-01-22:
Digressing somewhat, but a proof of principle in-software approach to kana chording on macOS!

This is a custom rule for the macOS Karabiner Elements software turning simultaneous use of "a" and "k" into "あ" (assuming the current input mode is "Unicode Hex Input", which could be done via another custom key mapping?):

```
{
    "description": "Pressing the a and k simultaneously sends kana か (ka)",
    "manipulators": [
        {
            "from": {
                "modifiers": { "optional": ["any"] },
                "simultaneous": [
                    { "key_code": "a" },
                    { "key_code": "k" }
                ],
                "simultaneous_options": { "key_down_order": "insensitive" }
            },
            "parameters": { "basic.simultaneous_threshold_milliseconds": 500 },
            "to": [
                { "sticky_modifier": { "left_option": "on" } },
                {
                    "key_code": "3",
                    "modifiers": "left_option"
                },
                {
                    "key_code": "0",
                    "modifiers": "left_option"
                },
                {
                    "key_code": "4",
                    "modifiers": "left_option"
                },
                {
                    "key_code": "2",
                    "modifiers": "left_option"
                },
                { "sticky_modifier": { "left_option": "off" } }
            ],
            "type": "basic"
        }
    ]
}
```

See https://karabiner-elements.pqrs.org/docs/json/complex-modifications-manipulator-definition/ etc for their documentation. The verbosity of their rules is a known issue - we'd need almost 100 rules just for the basic hiragana and katakana, but generating those could be automated.

I wouldn't use this on a normal keyboard, the current timings make typing the everyday combination of "a" and "k" troublesome, e.g. getting "あna" rather than "kana" if you type too fast.

However, I think this approach would work in principle with a custom secondary keyboard (where you could probably avoid using AIUEO as the "shift" keys and/or configure the software remapping to only apply to that keyboard).

e.g. Something like this split keyboard currently being sold on Ali Express, which has 3 rows of 5 on the left, and another 3 rows of 5 on the right:

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

peterjc, 2025-01-24:
I'm trying out some ideas based on this with the macOS Japanese input modes, and software remapping with Karabiner Elements.

Currently I am using an iOS flick-input like chording approach where any of the ASCII keys representing a row (like k for ka, ki, ku, ke, ko) can be pressed alone or in combination with one of four modifier keys (initially the four cursor keys) giving the five different vowel combinations:

https://github.com/peterjc/kana-chording-ke

Note that in macOS how to enter the kana depends on the current input mode - impossible in non-Japanese mode, by sending hex in "Unicode Hex Input" mode (as done by KanaChord), sending multiple key presses like `k` then `a` for か in "Japanese - Romaji" mode, and finally sending the matching key on the JIS layout in "Japanese - Kana" mode (`か` is on the `t` key). In either Japanese mode you then get kanji selection support 🤩

For the KanaChord project, I assume you emulate a HID keyboard. I think you would need a macOS language mode switch on the keyboard (just like how you currently switch between Linux, Windows, or macOS in hex mode), or assume the Mac computer is in the matching mode. There are macOS add-ons which will try to switch the language mode when a different physical keyboard is used, that might work here if for example using a USA layout laptop with an external KanaChord keyboard?

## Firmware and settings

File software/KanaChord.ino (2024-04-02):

/* KanaChord.ino */
/**
This file is part of KanaChord Keyboard.
 Copyright (C) 2024 Mac A. Cody

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
 You should have received a copy of the GNU General Public License
 along with this program.  If not, see <http://www.gnu.org/licenses/>.
**/

#include <Keyboard.h>
#include "kbd_mgt.h"
#define MODE_PIN_1 17
#define MODE_PIN_2 18

void setup() {
  // Set up inputs pins with internal pullups for USB keyboard macro
  // mode selection.  Switch has one end tied to ground to pull low.
  pinMode(MODE_PIN_1, INPUT_PULLUP);
  pinMode(MODE_PIN_2, INPUT_PULLUP);
  // Initialize the USB keyboard emulation.
  Keyboard.begin();
  kbd_setup();
}

void loop() {
  uint16_t kanaValue = kbd_process();

  if (kanaValue != 0x0000) {
    // Convert Unicode value to ASCII by first isolating each nybble.
    // Add ACSII '0' (48) if nybble less than 10, otherwise add ten
    // less than ASCII 'a' (97).
    uint8_t n0 = uint8_t (kanaValue >> 12);
    n0 = n0 < 10 ? 48 + n0 : 87 + n0;
    uint8_t n1 = uint8_t ((kanaValue >> 8) & 0x000f);
    n1 = n1 < 10 ? 48 + n1 : 87 + n1;
    uint8_t n2 = uint8_t ((kanaValue >> 4) & 0x000f);
    n2 = n2 < 10 ? 48 + n2 : 87 + n2;
    uint8_t n3 = uint8_t (kanaValue & 0x000f);
    n3 = n3 < 10 ? 48 + n3 : 87 + n3;

    int pin1 = digitalRead(MODE_PIN_1);
    int pin2 = digitalRead(MODE_PIN_2);
    if (pin1 == HIGH && pin2 == HIGH) {
      // Linux Unicode entry sequence.
      Keyboard.press(KEY_LEFT_SHIFT);
      delay(20);
      Keyboard.press(KEY_LEFT_CTRL);
      delay(20);
      Keyboard.write('u');
      Keyboard.write(n0);
      Keyboard.write(n1);
      Keyboard.write(n2);
      Keyboard.write(n3);
      Keyboard.releaseAll();
      delay(20);
    } else if (pin1 == HIGH && pin2 == LOW) {
      // Microsoft Windows Unicode entry sequence.
      Keyboard.write(n0);
      Keyboard.write(n1);
      Keyboard.write(n2);
      Keyboard.write(n3);
      Keyboard.press(KEY_LEFT_ALT);
      delay(20);
      Keyboard.press('x');
      delay(20);
      Keyboard.releaseAll();
      delay(20);
    } else if (pin1 == LOW && pin2 == HIGH) {
      // MacOS Unicode entry sequence.
      Keyboard.press(KEY_LEFT_ALT);
      delay(20);
      Keyboard.write(n0);
      Keyboard.write(n1);
      Keyboard.write(n2);
      Keyboard.write(n3);
      Keyboard.releaseAll();
      delay(20);
    }
  }
}

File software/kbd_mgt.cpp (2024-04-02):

/* kbd_mgt.cpp */
/**
This file is part of KanaChord Keyboard.
 Copyright (C) 2024 Mac A. Cody

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
 You should have received a copy of the GNU General Public License
 along with this program.  If not, see <http://www.gnu.org/licenses/>.
**/

#include <Arduino.h>

#include "Keypad2040.h"

#include <Adafruit_NeoPixel.h>
#include "kana.h"
#include "kbd_mgt.h"

//#define DEBUG 1

/*
 * The Adafruit Neokey board, which has five rows and six columns,
 * is broken between the third and fourth rows and set up as a
 * keyboard with three rows and twelve columns.  Note that the
 * left-most six columns only has two rows.
*/
#define ROWS 3
#define COLS 12
// Key groupings are differentiated by the value of the
// most-significant nybble.
#define CONSO_KEY 0
#define SHIFT_KEY 1
#define VOWEL_KEY 2
#define SPECL_KEY 3
/*
 * Rather than containing ASCII characters, the key array contains
 * codes for each key group.  The most significant nybble contains
 * the key group:
 * 0x0 - Consonant keys
 * 0x1 - Shift keys
 * 0x2 - Vowel keys
 * 0x3 - Special keys
 * 
 * The least sigificant nybble contains the indexing for the key group:
 * Consonant keys - Index is row of table.  Note: index of 0 implies vowels.
 * Shift keys - Index values: 0 = none, 1 = ten-ten, 2 = maru, 4 = chiisai.
 * Vowel keys - Index is column of table.
 * Special keys - Bits 0 - 3 for column index, bit 4 is row index.
  */
char keys[ROWS][COLS] = {
  {0x14,0x11,0x08,0x06,0x04,0x02,0x20,0x21,0x22,0x23,0x24,0x25},
  {0x12,0x09,0x07,0x05,0x03,0x01,0x30,0x31,0x32,0x33,0x34,0x35},
  {0x00,0x00,0x00,0x00,0x00,0x00,0x38,0x39,0x3a,0x3b,0x3c,0x3d},
};

// Arduino pins for the rows of the keypad.  RP Pico GPIO pin numbers.
byte rowPins[ROWS] = {12, 13, 14};
// Arduino pins for the columns of the keypad.  RP Pico GPIO pin numbers.
byte colPins[COLS] = {0, 1, 2, 3, 4, 5, 6, 7, 8, 9, 10, 11};

// Uncomment lines below to debug neopixels once keyboard is debugged.
// Pico GPIO pin number
#define NEOPIXEL_PIN 15 // RP Pico GPIO pin number
#define NUM_PIXELS 30 // Only 30 pixels in original neokey ordering.
Adafruit_NeoPixel strip = Adafruit_NeoPixel(NUM_PIXELS, NEOPIXEL_PIN, NEO_GRB + NEO_KHZ800);
#define GREENPIXEL 0x00006400
#define BLUEPIXEL 0x000000FF
#define REDPIXEL 0x00640000
#define WHITEPIXEL 0x00646464
#define KANAMODEKEY 5
#define KANAITERATE 11

/*
 * An approach to associating key values to neopixels is to use the index formed 
 * for each group to map to a specific neopixel.  Note that indexes that do not
 * map to a specific neopixel is set to -1.
 */
const int8_t consoColorKeys[] = {-1, 18, 29, 19, 28, 20, 27, 21, 26, 22};
const int8_t shiftColorKeys[] = {-1, 25, 23, -1, 24};
const int8_t vowelColorKeys[] = {12, 13, 14, 15, 16, 17};
const int8_t speclColorKeys[] = {11, 10, 9, 8, 7, 6, -1, -1, 0, 1, 2, 3, 4, -1};

// Note that press key indexes corresponding to color
// keys with value of -1 will never be set to true.
bool consoPressKeys[] = {false, false, false, false, false, false, false, false, false, false};
bool shiftPressKeys[] = {false, false, false, false, false};
bool vowelPressKeys[] = {false, false, false, false, false, false};
bool speclPressKeys[] = {false, false, false, false, false, false, false, false, false, false, false, false, false, false};

Keypad kpd = Keypad( makeKeymap(keys), rowPins, colPins, ROWS, COLS );

uint16_t getKanaUnicode(bool kana, bool special, uint8_t shift, uint8_t row, uint8_t col);

// Count of number of keys currently pressed for each key group.
byte consoCount;
byte shiftCount;
byte vowelCount;
byte speclCount;
byte indexRow, indexCol, shiftType;
bool kana, emit, speclKey; // Hirigana = false, Katakana = true.

/**
 * Function: kbd_setup - Initialze keyboard functionality,
 * e.g., keypad driver, keypad debounce, Neopixel driver.
 * Input: None.
 * Output: None.
 */
void kbd_setup(void) {
  consoCount = 0;
  shiftCount = 0;
  vowelCount = 0;
  speclCount = 0;
  kana = false;
  speclKey = false;
  indexRow = 0;
  indexCol = 0;
  shiftType = 0;
  
  /**
   * Initialize the Neopixels at start up.  Consonant, vowel, and
   * Kana mode, and iteration mark keys are green.  The remaining
   * special keys and shift keys are white.
   */
  strip.setPixelColor(KANAMODEKEY, GREENPIXEL);
  for (int i = 0; i < sizeof(consoColorKeys); i++) {
    if (consoColorKeys[i] != -1)
      strip.setPixelColor(consoColorKeys[i], GREENPIXEL);
  }
  for (int i = 0; i < sizeof(vowelColorKeys); i++) {
    if (vowelColorKeys[i] != -1)
      strip.setPixelColor(vowelColorKeys[i], GREENPIXEL);
  }

  strip.setPixelColor(speclColorKeys[0], GREENPIXEL);

  for (int i = 1; i < sizeof(speclColorKeys); i++) {
    if (speclColorKeys[i] != -1)
      strip.setPixelColor(speclColorKeys[i], WHITEPIXEL);
  }
  for (int i = 0; i < sizeof(shiftColorKeys); i++) {
    if (shiftColorKeys[i] != -1)
      strip.setPixelColor(shiftColorKeys[i], WHITEPIXEL);
  }
  strip.show();
  
  kpd.setDebounceTime(40); // 40 ms debounce works better that default 20 ms.
}
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

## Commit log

2024-03-09 Create Key2040.h
    Branch of Mark Stanley's Arduino Key class code to support Raspberry Pi RP2040 micro controller.
2024-03-09 Create Key2040.cpp
    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
2024-03-09 Create Keypad2040.cpp
    Branch of Mark Stanley's Arduino Keypad class code to support Raspberry Pi RP2040 micro controller.
2024-03-09 Create Keypad2040.h
    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
2024-03-09 Add files via upload
    Refactored keyboard case that requires no screws for assembly.
    [KanaChord-foot.stl, KanaChord-keybase-left.stl, KanaChord-keybase-right.stl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]
2024-03-21 Changed name of STL_files directory to hardware.
    [KanaChord-foot.stl]
2024-03-21 Moving STL files to hardware directory.
    [KanaChord-keybase-left.stl]
2024-03-30 Update left and right keypad assemblies in the Hardware README.md.
2024-03-30 Update to Electrical Assembly section of Hardware README.md.
2024-03-31 Update assembly portion of Hardware README.md.
2024-04-01 Update of final assembly steps in Hardware README.md.
2024-04-02 Update Software README.md.
    Added instructions for setting up, compiling, and uploading the KanaChord Keyboard software into the Raspberry Pi Pico.
2024-07-04 Updates to KanaChord case, base, and foot parts.
    Updated the KanaChord cases to provide better spacing of retention pegs for keyboard printed circuit boards. Updated the KanaChord bases to have square insertion holes for the feet. Updated the KanaChord foot design to have square pegs that are less likely to roll. These improvements are all 'back ports' from the rework performed for KanaChord Plus.
    [KanaChord-foot.stl, KanaChord-keybase-left.stl, KanaChord-keybase-right.stl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]
2024-07-04 Updated Hardware README.md file.
    Updated documentation due to changes in case, base, and foot STL files.

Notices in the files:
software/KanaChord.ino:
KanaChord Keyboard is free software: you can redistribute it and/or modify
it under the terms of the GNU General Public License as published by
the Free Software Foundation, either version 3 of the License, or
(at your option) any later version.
